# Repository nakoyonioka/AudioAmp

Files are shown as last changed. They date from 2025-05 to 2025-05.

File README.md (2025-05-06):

# Stereo Audio Amplifier (TPA3144D2)

This project implements a stereo audio amplifier circuit suitable for driving passive speakers. It utilizes the efficient Class-D architecture of the TPA3144D2, known for its low power consumption and relatively simple implementation.

## Features

* **Amplifier IC:** Based on the Texas Instruments TPA3144D2 stereo Class-D audio amplifier.
* **Output Power:** Capable of delivering up to 6W(details depend on power supply voltage and load impedance - refer to TPA3144D2 datasheet).
* **Stereo Output:** Provides two independent channels for stereo audio amplification.
* **Input Interface:** Designed for line-level stereo audio input.
* **Volume Control:** Includes interface points for connecting external potentiometers for independent left and right channel volume control.
* **Power Input:** Standard connector for DC power supply.
* **Speaker Outputs:** Screw terminals for easy connection of passive speakers.
* **Shutdown/Standby Control:** Includes provision for controlling the amplifier's operational state.

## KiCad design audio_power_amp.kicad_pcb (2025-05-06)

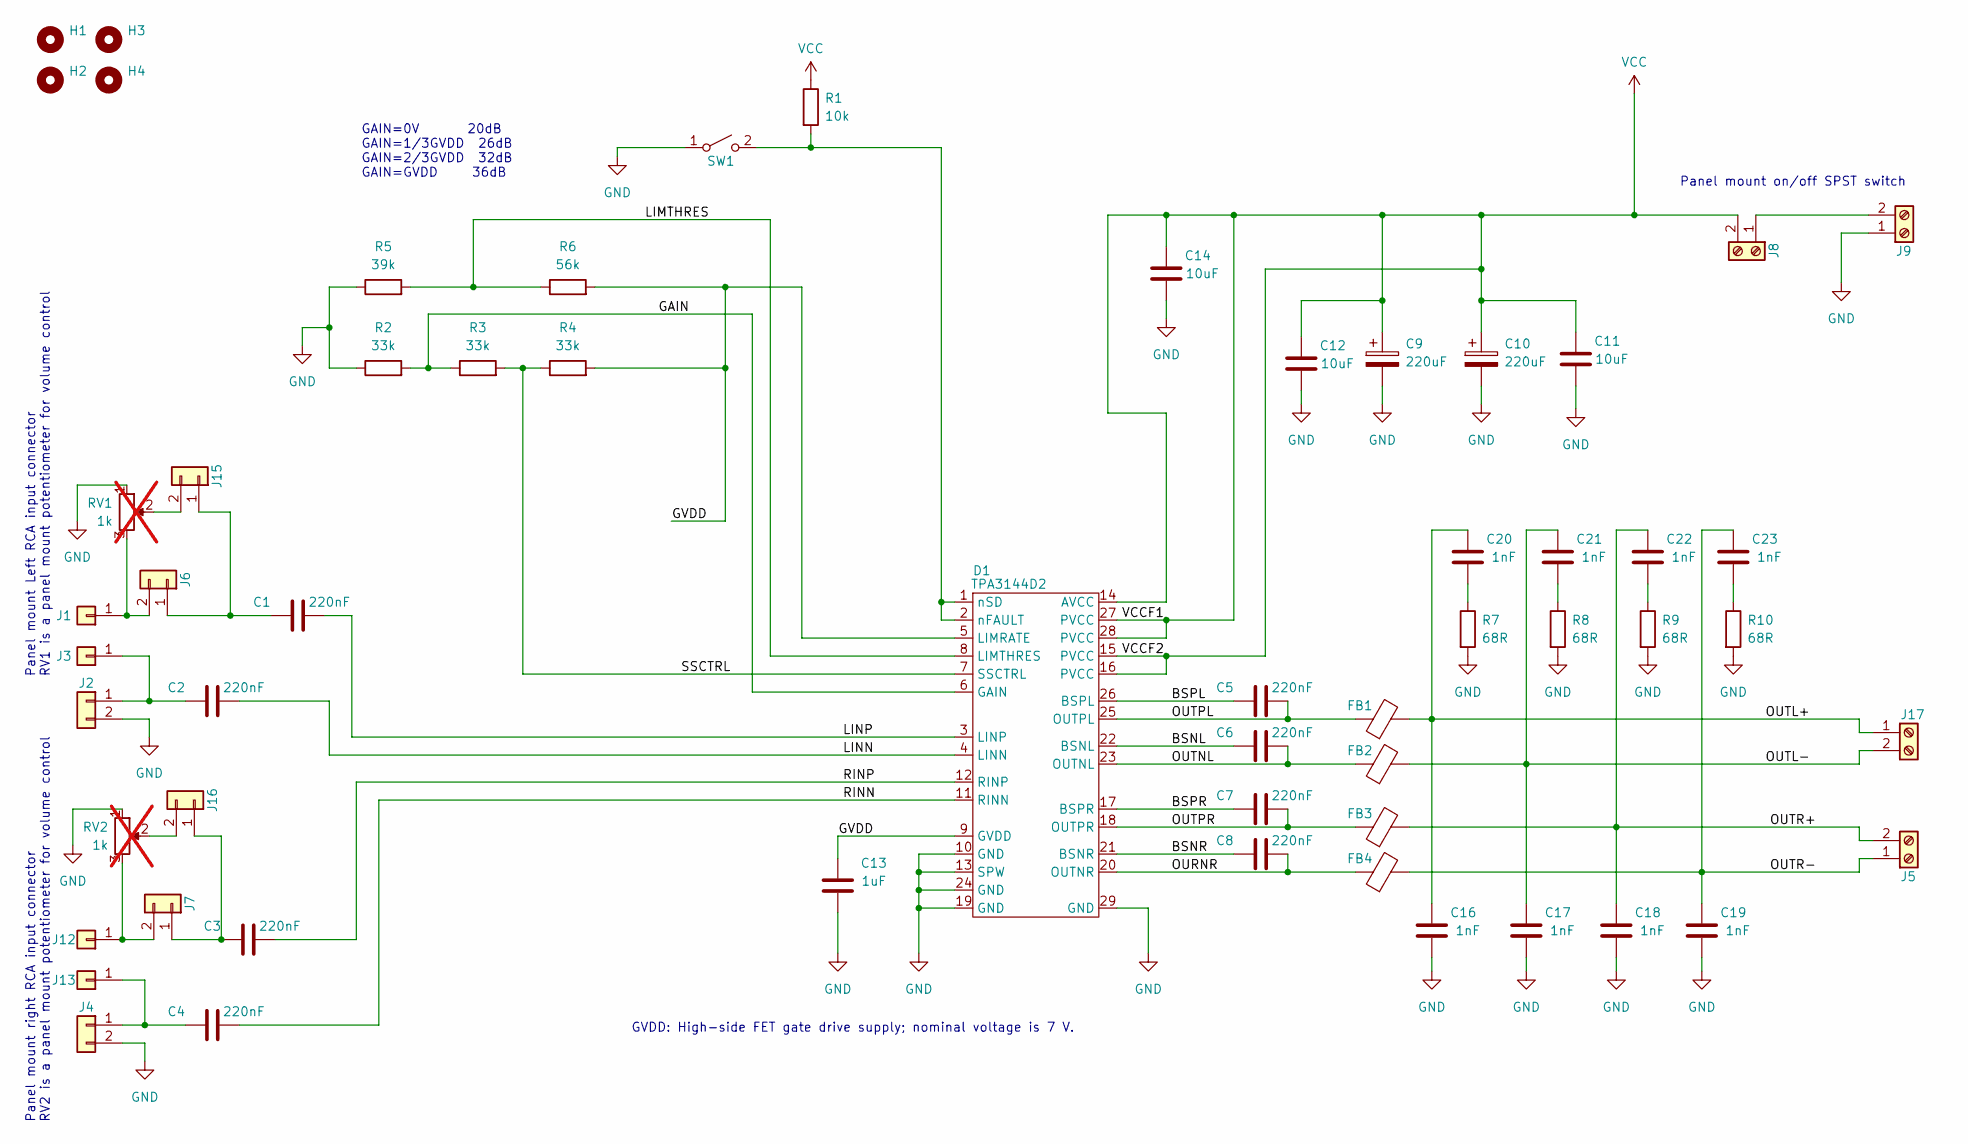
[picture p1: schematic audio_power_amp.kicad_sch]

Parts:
C1, C2, C3, C4: 220nF; C_0603_1608Metric_Pad1.08x0.95mm_HandSolder; LCSC PN C21120
C5, C6, C7, C8: 220nF; C_0603_1608Metric_Pad1.08x0.95mm_HandSolder; JLCPCB Type Basic
C9, C10: 220uF; CP_Radial_D10.0mm_P3.50mm
C11, C12, C14: 10uF; C_0805_2012Metric_Pad1.18x1.45mm_HandSolder; LCSC PN C440198
C13: 1uF; C_0603_1608Metric_Pad1.08x0.95mm_HandSolder; LCSC PN C15849
C16, C17, C18, C19, C20, C21, C22, C23: 1nF; C_0603_1608Metric_Pad1.08x0.95mm_HandSolder; LCSC PN C1588
D1: TPA3144D2; HTSSOP-28-1EP_4.4x9.7mm_P0.65mm_EP3.4x9.5mm_ThermalVias; LCSC PN C2860192
FB1, FB2, FB3, FB4: NFZ2MSM301SN10L; L_0805_2012Metric_Pad1.15x1.40mm_HandSolder; LCSC PN C668489
H1, H2, H3, H4: MountingHole; MountingHole_3.2mm_M3
J1, J3, J12, J13: Conn_01x01; PinHeader_1x01_P2.54mm_Vertical
J2, J4, J6, J7, J15, J16: Conn_01x02; PinHeader_1x02_P2.54mm_Vertical
J5, J8, J9, J17: Screw_Terminal_01x02; TerminalBlock_MetzConnect_Type086_RT03402HBLC_1x02_P3.81mm_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
R1: 10k; R_0805_2012Metric_Pad1.20x1.40mm_HandSolder; LCSC PN C17414
R2, R3, R4: 33k; R_0603_1608Metric_Pad0.98x0.95mm_HandSolder; LCSC PN C4216
R5: 39k; R_0603_1608Metric_Pad0.98x0.95mm_HandSolder; LCSC PN C23153
R6: 56k; R_0603_1608Metric_Pad0.98x0.95mm_HandSolder; LCSC PN C23206
R7, R8, R9, R10: 68R; R_0805_2012Metric_Pad1.20x1.40mm_HandSolder; LCSC PN C17802
RV1, RV2: 1k; PinHeader_1x03_P2.54mm_Vertical; not fitted
SW1: SW_SPST; SW_Tactile_Straight_KSA0Axx1LFTR

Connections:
/BSNL: C6.1, D1.22 (BSNL)
/BSNR: C8.1, D1.21 (BSNR)
/BSPL: C5.1, D1.26 (BSPL)
/BSPR: C7.1, D1.17 (BSPR)
/GAIN: D1.6 (GAIN), R2.2, R3.1
/GVDD: C13.2, D1.5 (LIMRATE), D1.9 (GVDD), R4.2, R6.2
/LIMTHRES: D1.8 (LIMTHRES), R5.2, R6.1
/LINN: C2.2, D1.4 (LINN)
/LINP: C1.2, D1.3 (LINP)
/OURNR: C8.2, D1.20 (OUTNR), FB4.1
/OUTL+: C16.2, C20.2, FB1.2, J17.1
/OUTL-: C17.2, C21.2, FB2.2, J17.2
/OUTNL: C6.2, D1.23 (OUTNL), FB2.1
/OUTPL: C5.2, D1.25 (OUTPL), FB1.1
/OUTPR: C7.2, D1.18 (OUTPR), FB3.1
/OUTR+: C18.2, C22.2, FB3.2, J5.2
/OUTR-: C19.2, C23.2, FB4.2, J5.1
/RINN: C4.2, D1.11 (RINN)
/RINP: C3.2, D1.12 (RINP)
/SSCTRL: D1.7 (SSCTRL), R3.2, R4.1
GND: C9.2, C10.2, C11.1, C12.1, C13.1, C14.1, C16.1, C17.1, C18.1, C19.1, D1.10 (GND), D1.13 (SPW), D1.19 (GND), D1.24 (GND), D1.29 (GND), J2.2, J4.2, J9.1, R2.1, R5.1, R7.2, R8.2, R9.2, R10.2, RV1.1, RV2.1, SW1.1 (A)
unnamed: C20.1, R7.1
unnamed: C21.1, R8.1
unnamed: C22.1, R9.1
unnamed: C23.1, R10.1
unnamed: D1.1 (nSD), D1.2 (nFAULT), R1.2, SW1.2 (B)
unnamed: J1.1, J6.2, RV1.3
unnamed: C2.1, J2.1, J3.1
unnamed: J8.1, J9.2
unnamed: J7.2, J12.1, RV2.3
unnamed: C4.1, J4.1, J13.1
unnamed: C1.1, J6.1, J15.1
unnamed: J15.2, RV1.2
unnamed: C3.1, J7.1, J16.1
unnamed: J16.2, RV2.2
VCC: C9.1, C10.1, C11.2, C12.2, C14.2, D1.14 (AVCC), D1.15 (PVCC), D1.16 (PVCC), D1.27 (PVCC), D1.28 (PVCC), J8.2, R1.1

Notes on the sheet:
GVDD: High-side FET gate drive supply; nominal voltage is 7 V.
Panel mount Left RCA input connector RV1 is a panel mount potentiometer for volume control
GAIN=0V 20dB GAIN=1/3GVDD 26dB GAIN=2/3GVDD 32dB GAIN=GVDD 36dB
Panel mount right RCA input connector RV2 is a panel mount potentiometer for volume control
Panel mount on/off SPST switch

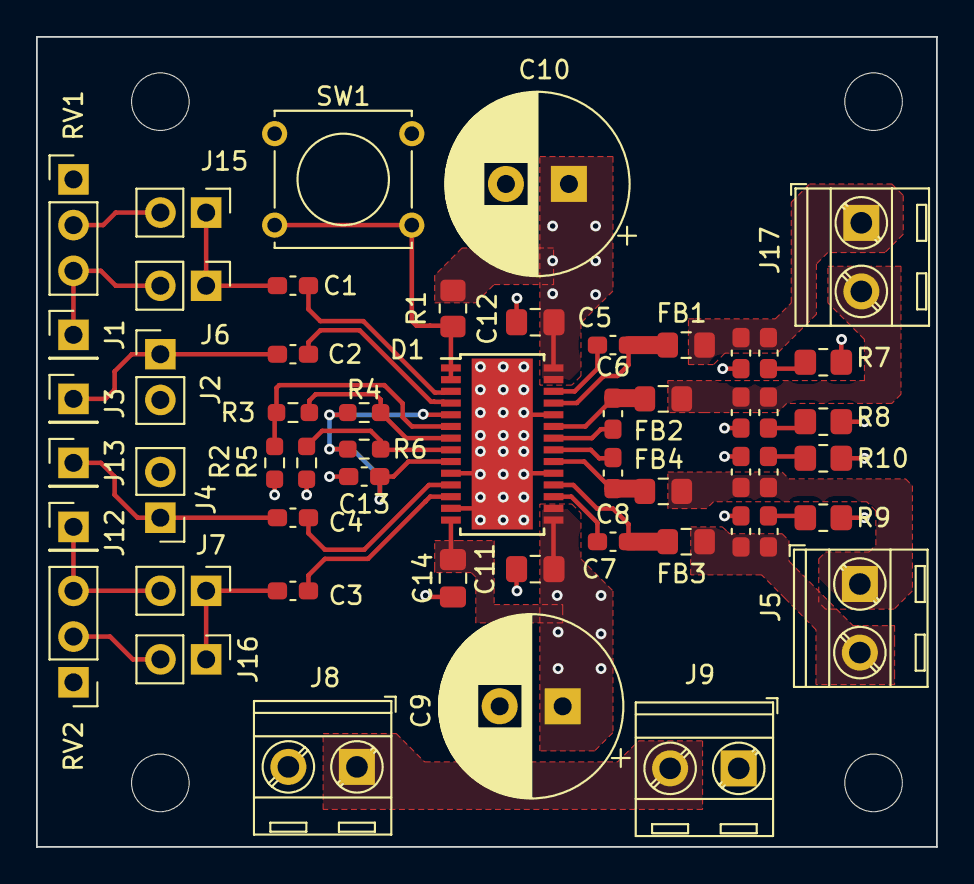
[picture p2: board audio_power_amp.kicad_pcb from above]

Board: 4 copper layers, 50.0 x 45.0 mm, 58 parts (0 on the bottom side), 36 nets.
